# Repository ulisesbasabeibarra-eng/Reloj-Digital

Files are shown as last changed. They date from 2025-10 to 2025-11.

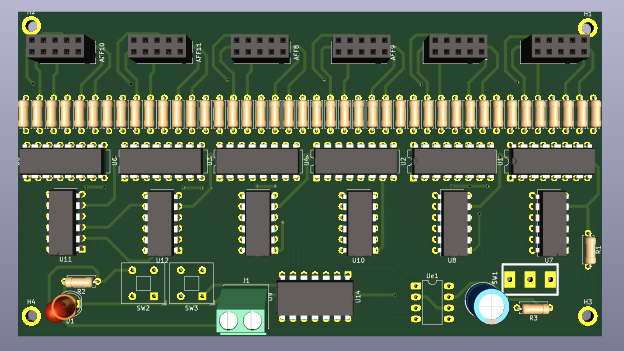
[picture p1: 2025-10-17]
placa/3D.png

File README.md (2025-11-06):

# Reloj Digital

(https://postimg.cc/QVPSPxDj)
## Authors

- [@Ulises Basabe](https://github.com/ulisesbasabeibarra-eng)
- [@Facundo Dominguez](https://github.com/facundodominguez1)
- [@Ramiro Trejo](https://github.com/RamiiTrejo)
- [@Rodrigo Benitez](https://github.com/rodrigobenitez17)
- [@Maximo Paez]()

## DESCRIPCIÓN

Un reloj digital sin utilizar un microcontrolador o web para establecer el tiempo. Utilizando solamente electronica discreta como el lm555, cuyo componente debe de estar en modo astable para general pulsos electronicos que estableceran gracias a los integrados 74LS47 y 74LS90 que los displays de 7 segmentos marquen una hora determinada. Un total de 6 displays para marcar los segundos, minutos y horas.
## Informe

[Video en proteus](https://www.youtube.com/watch?v=-MJHPHdGoc4)

[Reloj Digital](https://docs.google.com/document/d/12YXhhFJf7GPLBze2eZ5sYaiuNMOwRFxj9prBwNTrKLU/edit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)
. Este enlace lleva a un documento de google en el que se encuentra más informacion sobre este projecto junto con imagenes explicativas y vistas previas.
## Funcionamiento
El funcionamiento de este reloj se basa en el circuito integrado LM555, configurado como oscilador astable, que genera una serie de pulsos eléctricos aproximadamente de 1 Hz por  segundo. Estos pulsos son enviados al 74LS90, que actúa como contador decimal y convierte los pulsos en una salida binaria. Después, esta señal binaria pasa al 74LS47, que la decodifica y la transforma en señales para encender los segmentos correspondientes del display de 7 segmentos, mostrando así los números de forma digital. 

El potenciómetro permite ajustar la frecuencia del LM555, aumentando o disminuyendo la velocidad con que se generan los pulsos que llegan al 74LS90 (Es decir, la velocidad con que se cambian los números en el display).

El LED conectado al circuito también parpadea al ritmo de los pulsos, sirviendo como indicador visual de la frecuencia del contador. En este caso, se ha optado por utilizar una resistencia fija de 3,9 kΩ, de modo que el temporizador genere un pulso cada segundo aproximadamente, obteniendo así una base de tiempo estable para el reloj.

Los botones conectados uno a los displays de los segundos y otro conectado a los minutos. Su funcion es que una vez al ser pulsados, este pulso contara tambien como si fuera un pulso del LM555, es decir, una vez que se pulsa el numero del display pasara al siguiente respectivamente, funcionando como un reloj manual y esta para setiar el reloj a la hora exacta al de la hora actual.

(La alimentacion vendria mediante un cable conectado a un transformador el cual iria conectado a un toma corriente)
## Modelo 3D
En este projecto se utilizo Autodesk, plataforma de software el cual estoy mas acostumbrado a utilizar ademas de ser muy utilizadas a la hora de hacer diseños 3D, gracias a que este ofrece una amplia gama de software como AutoCAD, Fusion 360, Inventor y 3ds Max, utilizados en sectores como la ingeniería, la arquitectura, el entretenimiento y el diseño de productos.

El modelo 3D esta compuesto por dos partes principales: El piso y El cuerpo. 

El piso o la inferior, es un rectangulo compuesto por cuatro agujeros, uno en cada esquina, por donde se ingresarian los tornillos los cuales unirian las dos piezas. Además de tener otros cuatro agujeros más con un desnivel para ubicar la placa y mantenerla en el lugar y dejando un muy pequeño espacio entre los dos para las patas o sobresalientes de los componentes de la misma.

(https://postimg.cc/0KJsmph5)

El Cuepo tambien consta con los mismos huecos para tener mas rigidez en la uniones de estas tres partes (placa, piso, cuerpo).Tambien consta con un agujero en un costado para permitir la salida del cable de alimentación.

(https://postimg.cc/34FLqWpC)

Además tiene 6 agujeros rectangulares para permitir la vista de los displays de 7 segmento, con una pequeña separacion entre cada uno y otra entre cada grupo de dos, para formar los segundos, minutos y horas, cuyos grupos abajo les sigue sus respectivo unidad marcada como un corte en el cuerpo. Tambien, más abajo tiene dos agueros donde irian ubicados los botones. Los displays y los botones deberan ir adheridos con silicona para que mantengan su lugar.

(https://postimg.cc/LYGsr6pq)

En la carpeta carcasa, se encontran los archivos de estas pieza 3D en diferentes tipos de archivos desde .stl, donde se podran mandar a imprimir directamente, .fusion, asta .step. 
## Desmontaje de la carcasa
(https://a360.co/3W90Zk7)

 se observa como se vería el diseño de la plaqueta en 3D para poder dimensionar los componentes y facilitar la comprension de las conexiones

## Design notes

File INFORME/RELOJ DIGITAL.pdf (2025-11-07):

# RELOJ DIGITAL

Materia: Diseño Asistido y Simulación Electrónica

Profesor: Arguello Owen

Integrantes:
- Basabe Ulises
- Benitez Rodrigo
- Dominguez Facundo
- Paez Maximo
- Trejo Ramiro

Curso y división: 5°6 T.T

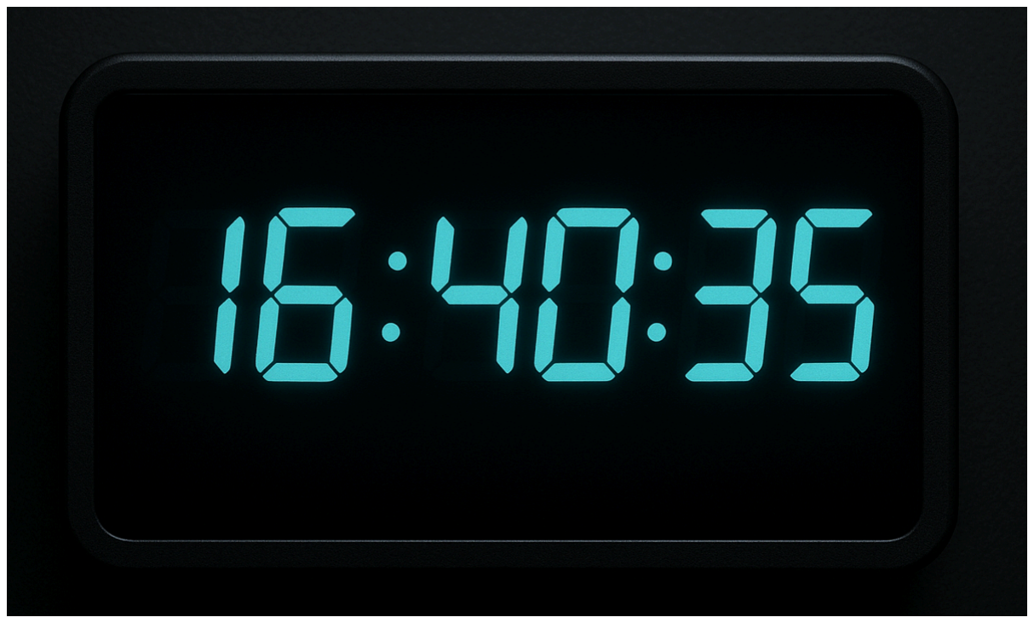
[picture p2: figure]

## PROYECTO

ÍNDICE:

PROYECTO | 2
INTRODUCCIÓN: | 3
FUNCIONAMIENTO | 3
DIAGRAMA DE FLUJO | 9
COMPONENTES | 10
SIMULACIÓN | 19
ESQUEMÁTICO | 26
PCB | 30
MODELO EN 3D (PCB) | 31
GABINETE | 32
GITHUB | 39
CONCLUSIÓN | 39

## INTRODUCCIÓN:

Este informe se basa en la idea de realizar un Reloj Digital sin el uso de un microcontrolador y con la utilización la electrónica discreta, por lo que en lugar del microcontrolador se emplean componentes lógicos tales como los integrados CD4081 (integrado de compuertas AND) 74LS32 (integrado de compuertas OR), 74LS47, 74LS90 y LM555, entre otros. Para luego hacer su esquemático, PCB, y la impresión 3D (Gabinete), la explicación de su funcionamiento, además del diagrama de flujos como explicación del funcionamiento del proyecto.

## FUNCIONAMIENTO

El funcionamiento de este reloj se basa en un circuito integrado LM555, configurado como oscilador astable, que genera una serie de pulsos eléctricos aproximadamente de 1 Hz por segundo. Estos pulsos son enviados al 74LS90, que actúa como contador decimal y convierte los pulsos en una salida binaria. Después, esta señal binaria pasa al 74LS47, que la decodifica y la transforma en señales (0 y 1 lógicos) para encender los segmentos correspondientes del display de 7 segmentos, mostrando así los números de forma digital.

El potenciómetro permite ajustar la frecuencia del LM555, aumentando o disminuyendo la velocidad con que se generan los pulsos que llegan al 74LS90 (Es decir, la velocidad con que se cambian los números en el display).

El LED conectado al circuito también parpadea al ritmo de los pulsos, sirviendo como indicador visual de la frecuencia del contador. En este caso, se ha optado por utilizar una resistencia fija de 3,9 kΩ, de modo que el temporizador genere un pulso cada segundo aproximadamente, obteniendo así una base de tiempo estable para el reloj.

## FUNCIONAMIENTO DE LOS COMPONENTES

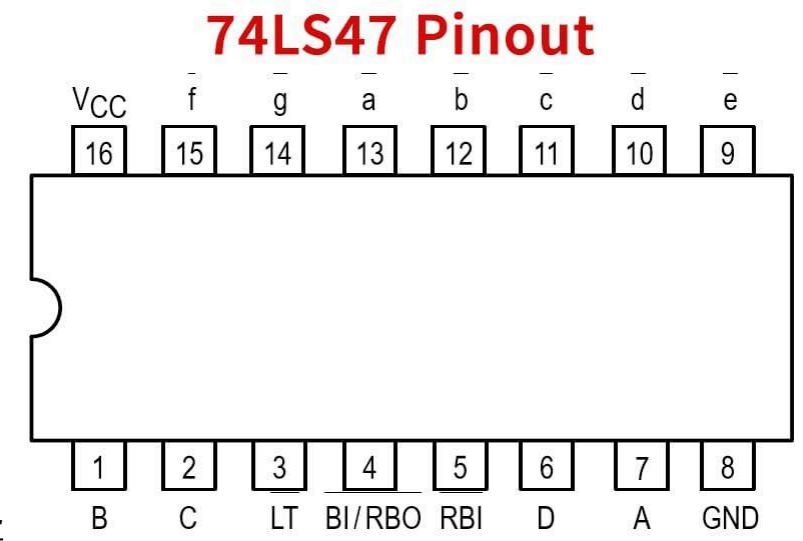
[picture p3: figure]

74LS47:

El 74LS47 es un decodificador/driver para un display de 7 segmentos de cátodo común, convierte un número binario de 0 a 9 en código BCD (código binario), en las señales necesarias para mostrarlo de forma visual en el display

1. A–D (pines 7,1,2,6): entran desde el contador → llevan el número en binario.
2. LT, RBI, BI (pines 3,4,5): todos a Vcc → se desactivan funciones extra.
3. a–g (pines 9–15): van al display → forman el número visible.
4. Vcc y GND (16 y 8): alimentación 5 V.

74LS90:

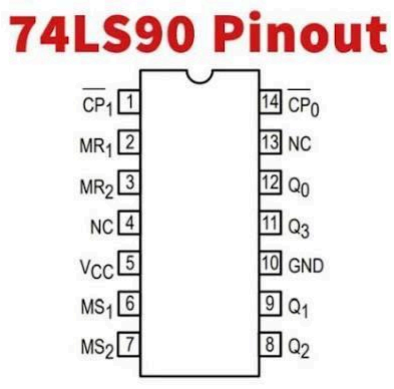
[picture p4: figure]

El 74LS90 es un contador de pulsos (señales de reloj) de 0 a 9 en binario , y después vuelve a cero automáticamente, Por eso se lo llama contador BCD, (generalmente se usa para contadores digitales como relojes, cronómetros etc. y también se combina como en este caso con el 74LS47 para mostrar los números en el display de 7 segmentos.

Pin 14 (CP1 o CLKA) → Entrada de reloj (clock).

Pin 1 (CP0 o CLKB) → Entrada de reloj secundaria.

Pin 2 (R0(1)) y Pin 3 (R0(2)) → Reset asíncrono. (Pin de reset)

Pin 6 (R9(1)) y Pin 7 (R9(2)) → Set asíncrono a 1001 (decimal 9).

Pin 12 (Q0), Pin 9 (Q1), Pin 8 (Q2), Pin 11 (Q3)

Son las salidas binarias del contador.

Van conectadas directamente a las entradas A–D del 74LS47.

Pin 5 (GND) → Masa del circuito.

Pin 10 (Vcc) → +5 V.

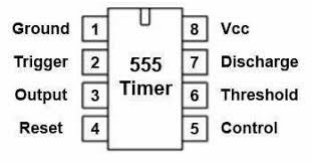
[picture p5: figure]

LM555:

El LM555 es un temporizador / generador de pulsos que trabaja de tres maneras principales:

Monoestable: Genera un solo pulso de duración fija

Astable: Genera una onda cuadrada continua como si fuera un reloj o parpadeo

Biestable: Funciona como un flip flop es decir, enciende o apaga una salida

1. GND (pin 1) → A tierra (masa).

Referencia de voltaje.

2. TRIG (pin 2) → Disparo del comparador.
3. OUT (pin 3) → Salida de onda cuadrada.

Va hacia los contadores (74LS90) → genera los pulsos de conteo.

También va al LED (con R2) para ver el parpadeo.

4. RESET (pin 4) → Reinicia el temporizador.

Lo tienes a Vcc (5V) para desactivarlo (no quieres resetear el oscilador).

5. CTRL (pin 5) → Voltaje de control.

Está conectado a tierra con un capacitor de desacoplo (no se usa en esta aplicación).

6. THR (pin 6) → Umbral del comparador.

Se conecta al capacitor (C1) y al pin 2 (TRIG).

7. DIS (pin 7) → Descarga.

Se conecta entre el capacitor y la resistencia/potenciómetro → controla la descarga del capacitor C1.

8. VCC (pin 8) → Alimentación (+5 V).

### DIAGRAMA DE FLUJO

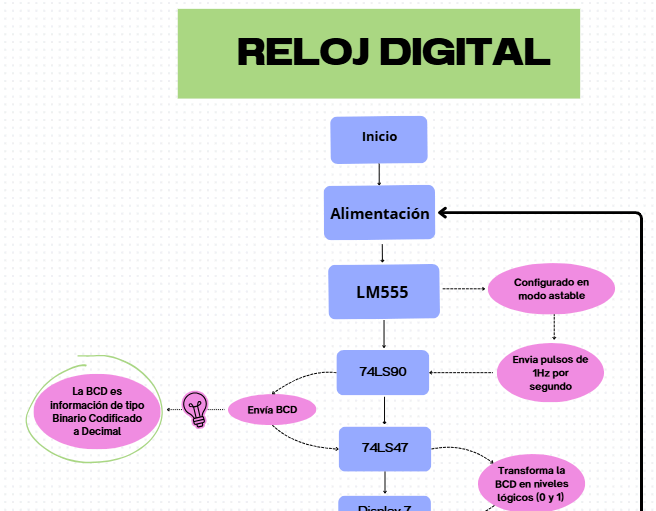
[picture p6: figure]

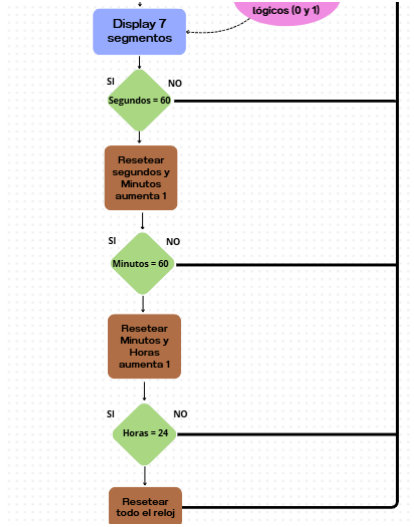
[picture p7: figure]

En este diagrama de flujo se puede observar cómo funciona el Reloj Digital de una manera fácil y sencilla

### COMPONENTES

COMPONENTE | CANTIDAD | IMAGEN DE REFERENCIA

Pineras doble fila (2x05) | 6
Pineras hembra doble fila (2x02) | 2
Zócalo 8 pines (2x04) | 1
Zócalo 12 pines (2x06) | 6

Zócalo 14 pines (2x07) | 7
Zócalo 16 pines (2x08) | 6
Resistencia SMD 330Ω 1206 | 43
Resistencia SMD 4,7kΩ 1206 | 1
Resistencia SMD 3.9kΩ 1206 | 1

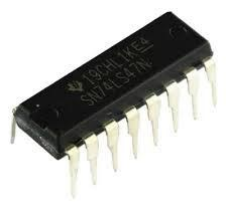
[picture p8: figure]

74LS47 | 6
74LS90 | 6
LM555 | 1

CD4081 | 2
74LS32 | 5
Led | 1

Capacitor (10uF) | 1
Displays de 7 segmentos | 6

## SIMULACIÓN

Para la parte de la simulación y pruebas del proyecto Reloj Digital se utilizó el software de simulación y diseño de plaquetas Proteus, el cuál incluye una amplia variedad de componentes electrónicos y una interfaz muy intuitiva.

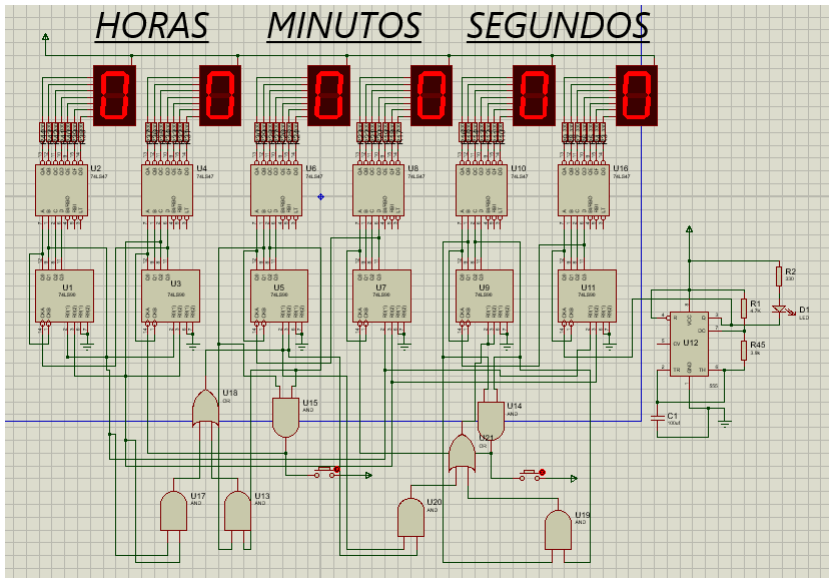
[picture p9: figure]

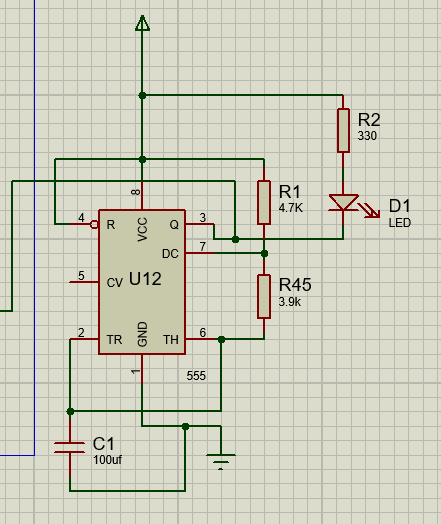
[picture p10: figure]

En esta imagen se muestra como es la conexión del LM555 para que genere los pulsos en modo astable.

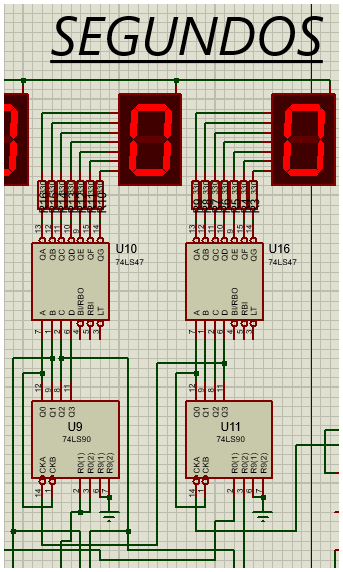
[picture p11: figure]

En esta otra se muestra como los pulsos son recibidos por el primer 74LS90 de todo el circuito (el de los segundos), que recibe los pulsos y los convierte en BCD (decimal codificado en binario en español) para que el 74LS47 transforme esos números en binario en señales (señales lógicas, 0 y 1) dando como resultado un número determinado. Luego mediante el pin de “carry out” (que indica un desbordamiento en este caso de bits) cuando este llega al número 9 (1001 en binario) genera el “carry out” y hace que aumente las decenas de segundos para que luego cuando este llegue a 5 y las unidades de segundos lleguen a 9 el próximo número sea un 1 en las unidades de los minutos.

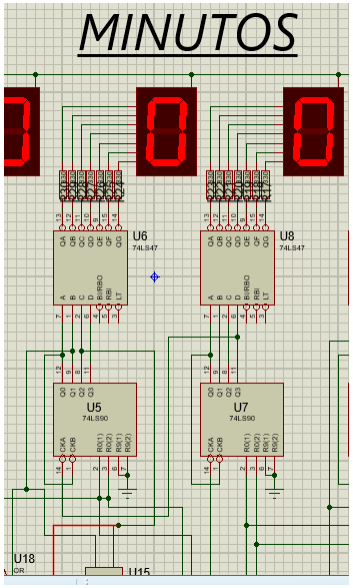
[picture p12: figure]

Este posee la misma funcionalidad que los segundos con la diferencia que posee un pulsador con el que se puede setear los minutos y que cuando llegue a 59 y los segundos esten en 59, el siguiente pulso aumentará las unidades de las horas

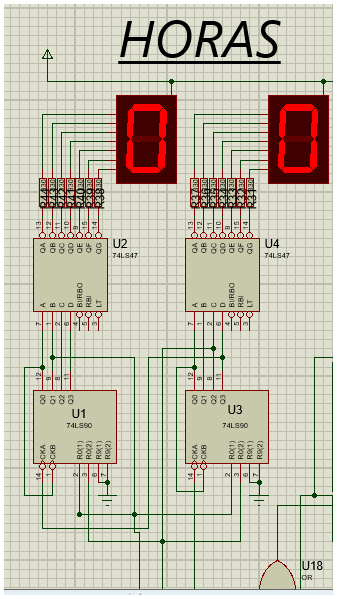
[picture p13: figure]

Este posee una lógica similar solamente que las unidades de horas llegan hasta 3 y las decenas llegan a 2 teniendo que por consecuencia cuando la hora marque 24 Horas el siguiente número será el reseteo del reloj, volviendo así a comenzar.

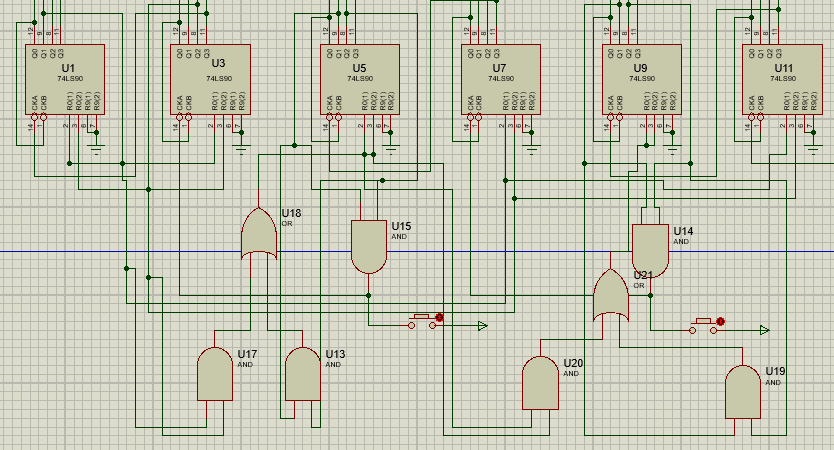
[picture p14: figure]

Aquí se muestra como en las horas y los minutos está la opción para setearlos mediante los pulsadores.
El seteo de la hora se basa en enviar pulsos manuales a las entradas de reloj de los contadores 74LS90, que de igual manera se da cuando los minutos o los segundos llegan a 60, haciendo que aumente las horas o los minutos.

Luego para hacer que se reseteen se hace cuando cualquiera de las dos condiciones se de, cuando los minutos alcanzan 60 o cuando las horas llegan a 24.
Esto se logra conectando la salida de la OR a los pines de reset de los contadores (R₁ y R₂) del 74LS90.
De esta forma, el circuito puede volver a cero automáticamente. Las compuertas AND se utilizan para cuando se dan las opciones de reseteo se marque como un uno lógico y esa señal se envía luego a la compuerta OR, que activa los pines de reset de los contadores, haciendo que los minutos (o segundos) vuelvan a cero. Lo mismo sucede cuando se llega a 24 (en las horas) haciendo que se resetee todo el reloj

En el siguiente enlace se muestra el funcionamiento del proyecto Reloj Digital simulado en Proteus: https://www.youtube.com/watch?v=-MJHPHdGoc4

## ESQUEMÁTICO

El diseño esquemático para la placa se realizó en el software de diseño de placas KICAD, el cual con suma facilidad permite diseñar el esquema y conexiones de componentes, con una interfaz muy intuitiva y una amplia variedad de diseños de componentes.

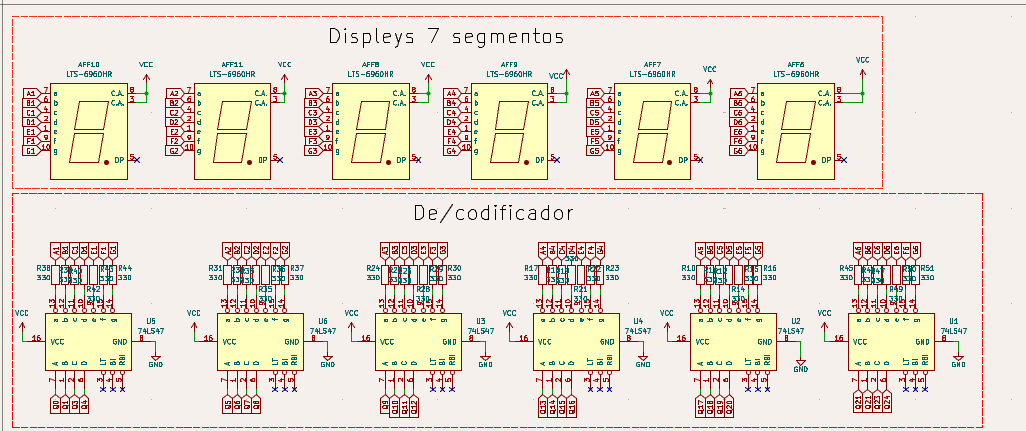
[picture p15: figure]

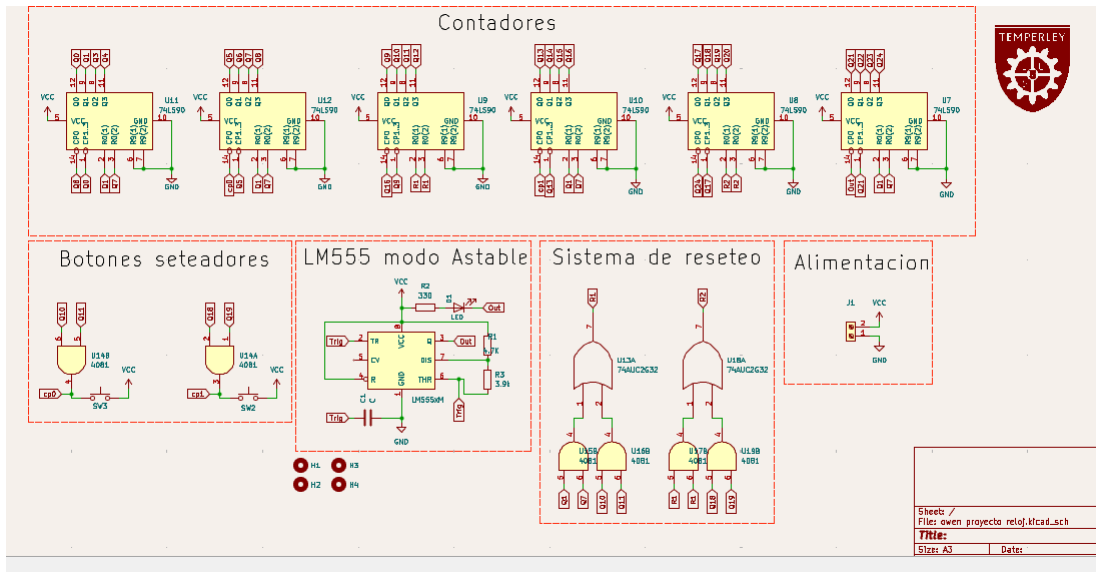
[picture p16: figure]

Y acá se encuentran fotos del esquemático (declaración de pines, decodificadores displays, integrados, etc)

Lo siguiente sería cómo se compone cada parte en general, primero viene el 74LS90, después le sigue el 74LS47 y por último los displays

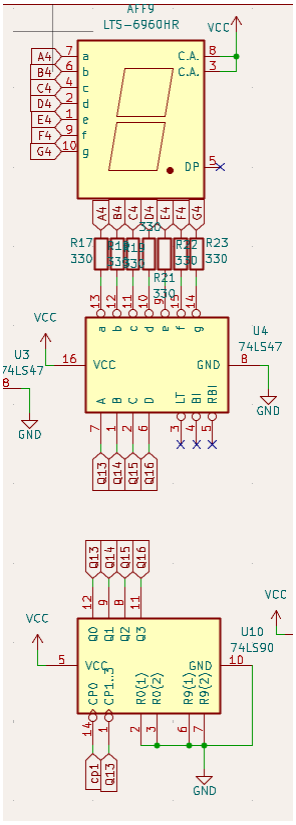
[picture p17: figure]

## PCB

El diseño PCB (placa de circuito impreso en español) se realizó de igual manera en la plataforma de software libre KICAD el cual además de poder realizar esquemas de diseños, también se puede realizar el diseño de la PCB, el cual posee una amplia variedad de huellas (formas de los componentes).
El diseño de la PCB se compone de la siguiente manera

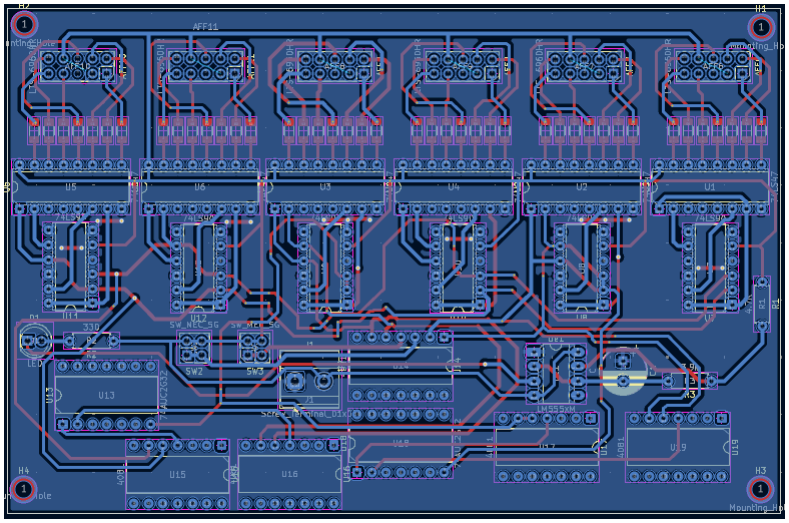
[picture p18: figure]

De esta forma queda el diseño para no desperdiciar espacio y mantener una mejor optimización de los componentes.

## MODELO EN 3D (PCB)

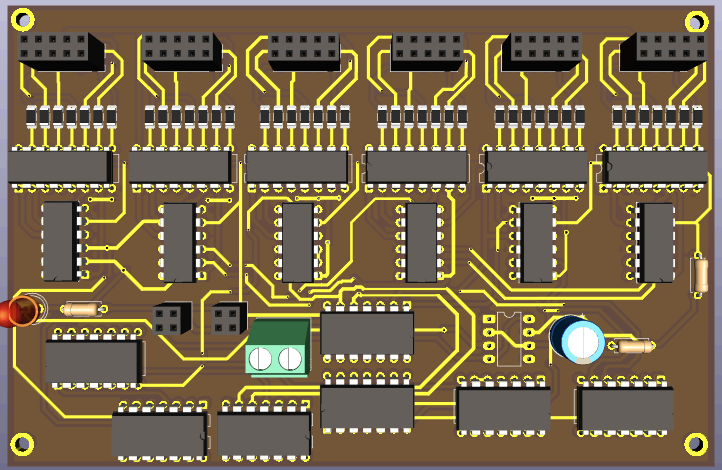
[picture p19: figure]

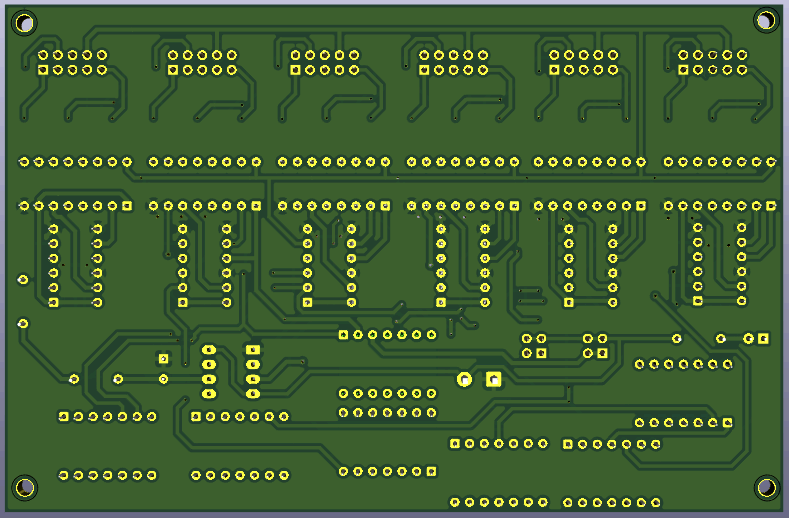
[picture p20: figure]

De esta manera se observa como es la distribución de los componentes desde un diseño de plaqueta de doble cara (también conocido como doble faz) para una mejor optimización y eficiencia del espacio.

## GABINETE

Este diseño se realizó en la aplicación de software de diseño 3D profesional, Autodesk Fusión 360, la cual posee una gran cantidad de herramientas para realizar diseños de tal magnitud, y con una mayor precisión que otros softwares de diseño.
Ahora veremos el modelo 3D del gabinete para poner los displays, la placa y como conectarse a la alimentación.

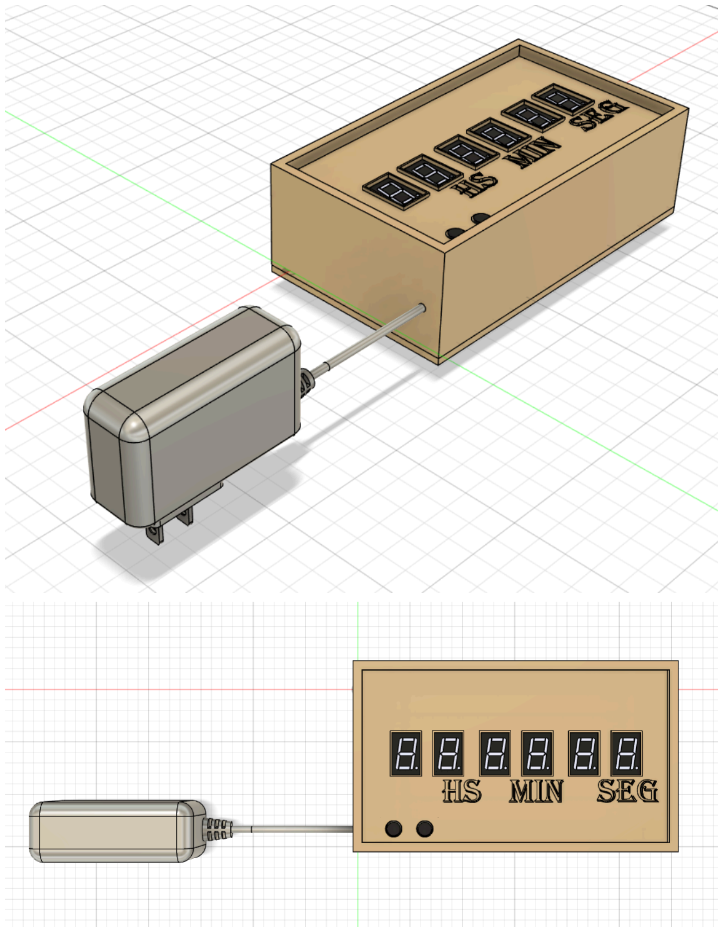
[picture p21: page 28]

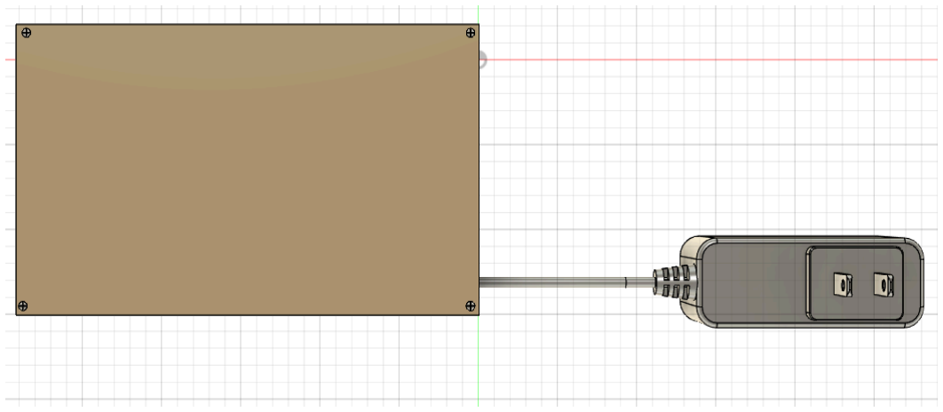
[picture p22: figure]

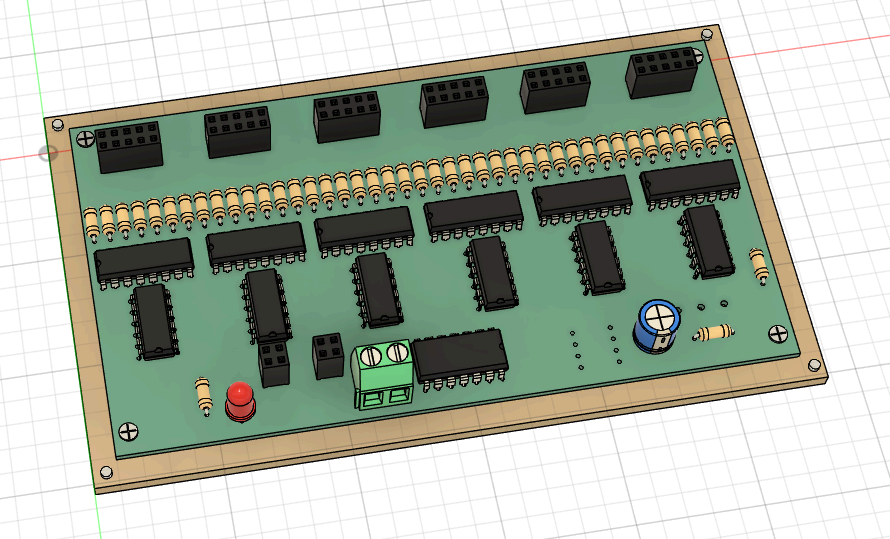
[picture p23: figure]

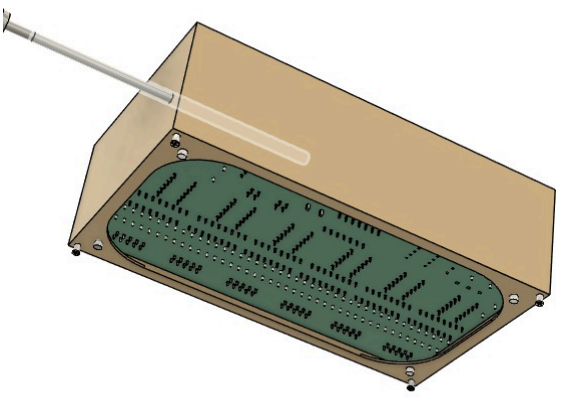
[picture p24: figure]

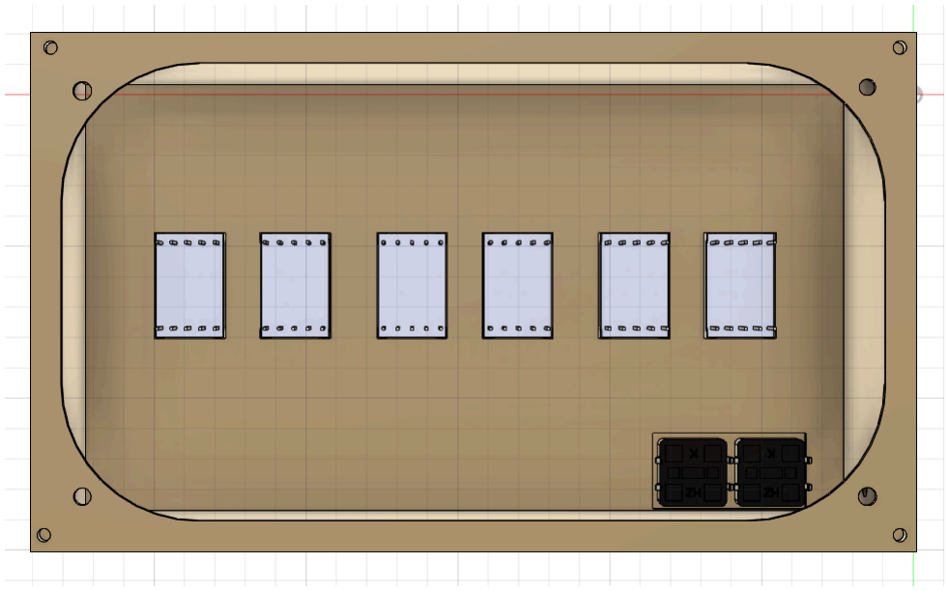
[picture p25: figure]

## GITHUB

A continuación se deja el enlace a la plataforma GITHUB donde se ha subido todo el proyecto y que permite visualizar las diferentes categorías del proyecto, y poder realizar las pruebas por cuenta propia.
https://github.com/ulisesbasabeibarra-eng/Reloj-Digital

## CONCLUSIÓN

Este proyecto permitió poner en práctica los conocimientos adquiridos en electrónica, aplicándolos de manera concreta en la realización de un reloj de 24 horas. A lo largo del desarrollo se pudo comprender de forma más profunda el funcionamiento interno de los distintos componentes electrónicos que componen la electrónica discreta, especialmente los circuitos integrados que hacen posible la secuencia y el conteo de tiempo. Además de poder profundizar el aprendizaje en las aplicaciones tanto como de simulación del circuito, como de la creación de la PCB o el diseño 3D

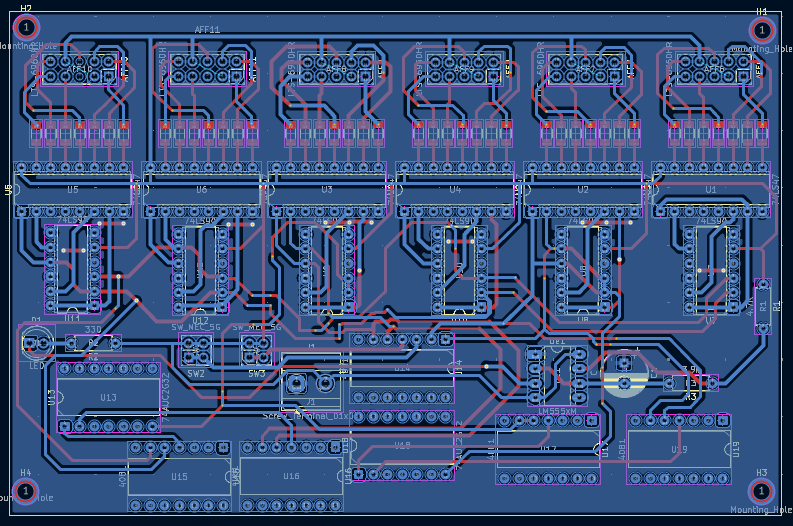
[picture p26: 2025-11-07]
placa/PCB.png

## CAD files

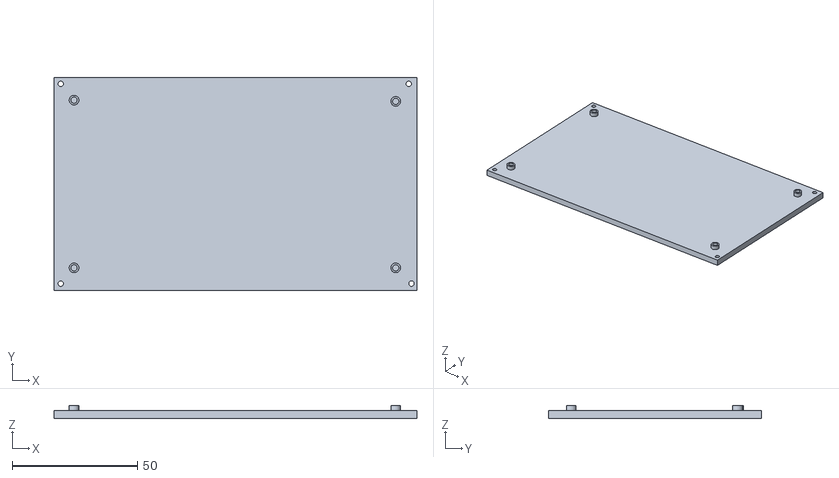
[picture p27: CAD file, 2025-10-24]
Carcasa/Objetos 3d/Reloj carcasa piso.stl
145.0 x 85.0 x 5.00

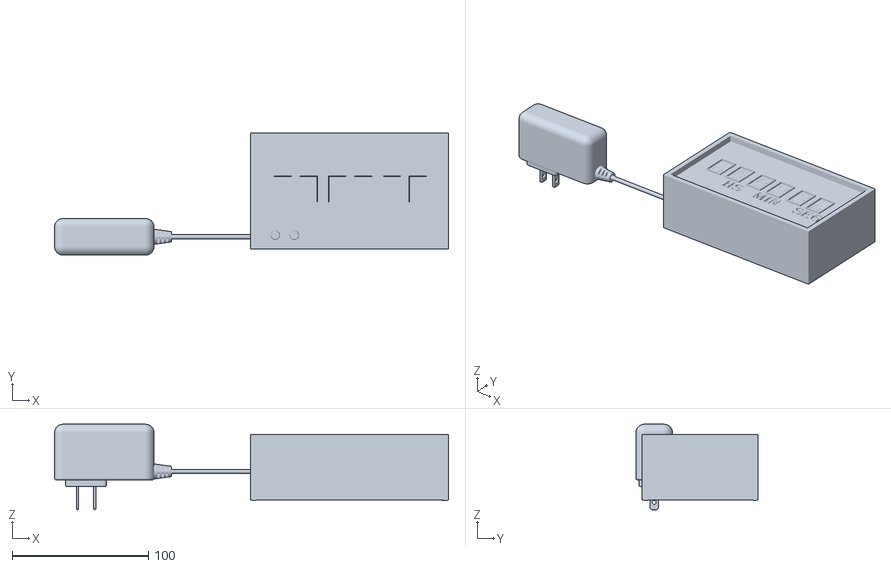
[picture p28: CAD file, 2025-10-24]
Carcasa/Reloj carcasa v10.stl
288.8 x 89.7 x 62.8

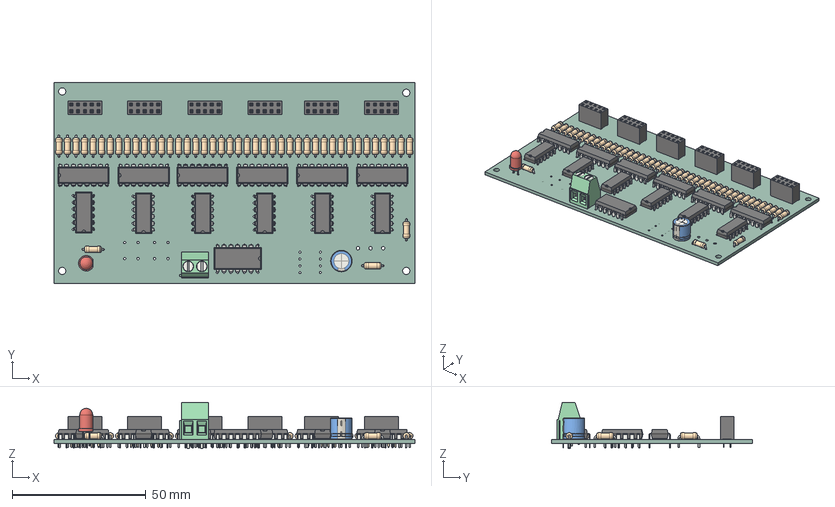
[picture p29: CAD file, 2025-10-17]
placa/pcb y esquematico/owen proyecto reloj.step
134.8 x 74.9 x 17.3 mm
R_Axial_DIN0207_L6.3mm_D2.5mm_P7.62mm_Horizontal x 45
PinSocket_2x05_P2.54mm_Vertical x 6
DIP-16_W7.62mm x 6
DIP-12_W7.62mm x 6
LED_D5.0mm
CP_Radial_D8.0mm_P3.50mm
DIP-14_W10.16mm
TerminalBlock_Phoenix_MKDS-1,5-2-5.08_1x02_P5.08mm_Horizontal
owen proyecto reloj_PCB

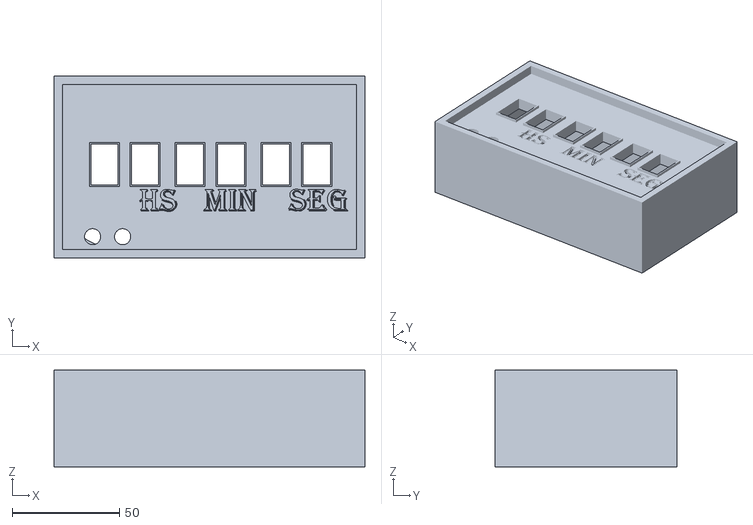
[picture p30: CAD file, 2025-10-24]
Carcasa/Objetos 3d/Reloj carcasa cuerpo.stl
145.0 x 85.0 x 45.0

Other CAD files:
Carcasa/Reloj carcasa v9.f3z

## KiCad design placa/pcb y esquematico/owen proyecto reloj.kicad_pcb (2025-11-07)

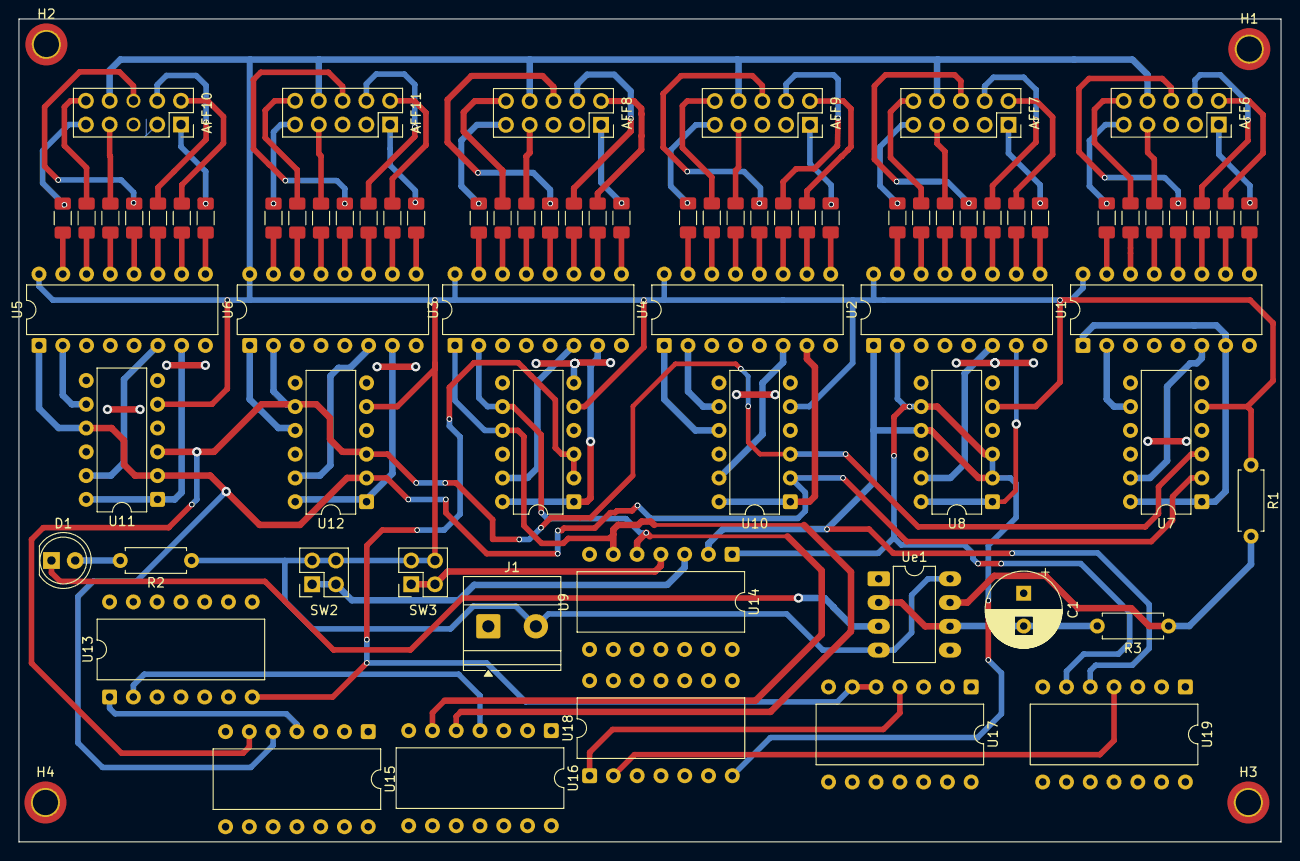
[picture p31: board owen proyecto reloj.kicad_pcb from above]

Board: 2 copper layers, 134.8 x 87.9 mm, 80 parts (0 on the bottom side), 121 nets.

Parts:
AFF6, AFF7, AFF8, AFF9, AFF10, AFF11: LTS-6960HR; PinSocket_2x05_P2.54mm_Vertical
C1: C; CP_Radial_D8.0mm_P3.50mm
D1: LED; LED_D5.0mm
H1, H2, H3, H4: Mounting_Hole; MountingHole_2.7mm_M2.5_ISO14580_Pad_TopOnly
J1: Screw_Terminal_01x02; TerminalBlock_Phoenix_MKDS-1,5-2-5.08_1x02_P5.08mm_Horizont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
R1: 4.7K; R_Axial_DIN0207_L6.3mm_D2.5mm_P7.62mm_Horizontal
R2: 330; R_Axial_DIN0207_L6.3mm_D2.5mm_P7.62mm_Horizontal
R3: 3.9k; R_Axial_DIN0207_L6.3mm_D2.5mm_P7.62mm_Horizontal
R10, R11, R12, R13, R14, R15, R16, R17, R18, R19, R20, R21, R22, R23, R24, R25, R26, R27, R28, R29, R30, R31, R32, R33, R34, R35, R36, R37, R38, R39, R40, R41, R42, R43, R44, R45, R46, R47, R48, R49, R50, R51: 330; R_1206_3216Metric_Pad1.30x1.75mm_HandSolder
SW2, SW3: SW_MEC_5G; PinSocket_2x02_P2.54mm_Vertical
U1, U2, U3, U4, U5, U6: 74LS47; DIP-16_W7.62mm
U7, U8, U9, U10, U11, U12: 74LS90; DIP-12_W7.62mm
U13, U18: 74AUC2G32; DIP-14_W10.16mm
U14, U15, U16, U17, U19: 4081; DIP-14_W10.16mm
Ue1: LM555xM; DIP-8_W7.62mm_LongPads

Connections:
A1: AFF10.7 (a), R38.1
A2: AFF11.7 (a), R31.1
A3: AFF8.7 (a), R24.1
A4: AFF9.7 (a), R17.1
A5: AFF7.7 (a), R10.1
A6: AFF6.7 (a), R45.1
B1: AFF10.6 (b), R39.1
B2: AFF11.6 (b), R32.1
B3: AFF8.6 (b), R25.1
B4: AFF9.6 (b), R18.1
B5: AFF7.6 (b), R11.1
B6: AFF6.6 (b), R46.1
C1: AFF10.4 (c), R40.1
C2: AFF11.4 (c), R33.1
C3: AFF8.4 (c), R26.1
C4: AFF9.4 (c), R19.1
C5: AFF7.4 (c), R12.1
C6: AFF6.4 (c), R47.1
D1: AFF10.2 (d), R41.1
D2: AFF11.2 (d), R34.1
D3: AFF8.2 (d), R27.1
D4: AFF9.2 (d), R20.1
D5: AFF7.2 (d), R13.1
D6: AFF6.2 (d), R48.1
E1: AFF10.1 (e), R42.1
E2: AFF11.1 (e), R35.1
E3: AFF8.1 (e), R28.1
E4: AFF9.1 (e), R21.1
E5: AFF7.1 (e), R14.1
E6: AFF6.1 (e), R49.1
F1: AFF10.9 (f), R43.1
F2: AFF11.9 (f), R36.1
F3: AFF8.9 (f), R29.1
F4: AFF9.9 (f), R22.1
F5: AFF7.9 (f), R15.1
F6: AFF6.9 (f), R50.1
G1: AFF10.10 (g), R44.1
G2: AFF11.10 (g), R37.1
G3: AFF8.10 (g), R30.1
G4: AFF9.10 (g), R23.1
G5: AFF7.10 (g), R16.1
G6: AFF6.10 (g), R51.1
GND: C1.1, J1.1, U1.8 (GND), U2.8 (GND), U3.8 (GND), U4.8 (GND), U5.8 (GND), U6.8 (GND), U7.6 (R9(1)), U7.7 (R9(2)), U7.10 (GND), U8.6 (R9(1)), U8.7 (R9(2)), U8.10 (GND), U9.6 (R9(1)), U9.7 (R9(2)), U9.10 (GND), U10.6 (R9(1)), U10.7 (R9(2)), U10.10 (GND), U11.6 (R9(1)), U11.7 (R9(2)), U11.10 (GND), U12.6 (R9(1)), U12.7 (R9(2)), U12.10 (GND), Ue1.1 (GND)
unnamed: D1.2 (A), R2.2
unnamed: R45.2, U1.13 (a)
unnamed: R46.2, U1.12 (b)
unnamed: R47.2, U1.11 (c)
unnamed: R48.2, U1.10 (d)
unnamed: R49.2, U1.9 (e)
unnamed: R50.2, U1.15 (f)
unnamed: R51.2, U1.14 (g)
unnamed: R10.2, U2.13 (a)
unnamed: R11.2, U2.12 (b)
unnamed: R12.2, U2.11 (c)
unnamed: R13.2, U2.10 (d)
unnamed: R14.2, U2.9 (e)
unnamed: R15.2, U2.15 (f)
unnamed: R16.2, U2.14 (g)
unnamed: R24.2, U3.13 (a)
unnamed: R25.2, U3.12 (b)
unnamed: R26.2, U3.11 (c)
unnamed: R27.2, U3.10 (d)
unnamed: R28.2, U3.9 (e)
unnamed: R29.2, U3.15 (f)
unnamed: R30.2, U3.14 (g)
unnamed: R17.2, U4.13 (a)
unnamed: R18.2, U4.12 (b)
unnamed: R19.2, U4.11 (c)
unnamed: R20.2, U4.10 (d)
unnamed: R21.2, U4.9 (e)
unnamed: R22.2, U4.15 (f)
unnamed: R23.2, U4.14 (g)
unnamed: R38.2, U5.13 (a)
unnamed: R39.2, U5.12 (b)
unnamed: R40.2, U5.11 (c)
unnamed: R41.2, U5.10 (d)
unnamed: R42.2, U5.9 (e)
unnamed: R43.2, U5.15 (f)
unnamed: R44.2, U5.14 (g)
unnamed: R31.2, U6.13 (a)
unnamed: R32.2, U6.12 (b)
unnamed: R33.2, U6.11 (c)
unnamed: R34.2, U6.10 (d)
unnamed: R35.2, U6.9 (e)
unnamed: R36.2, U6.15 (f)
unnamed: R37.2, U6.14 (g)
unnamed: U13.1, U15.4
unnamed: U13.2, U16.4
unnamed: U17.4, U18.1
unnamed: U18.2, U19.4
unnamed: R1.2, R3.1, Ue1.7 (DIS)
Out: D1.1 (K), Ue1.3 (Q)
Q0: U5.7 (A), U11.1 (CP1..3), U11.12 (Q0)
Q1: U5.1 (B), U7.2 (R0(1)), U10.2 (R0(1)), U11.2 (R0(1)), U11.9 (Q1), U12.2 (R0(1)), U15.5
Q3: U5.2 (C), U11.8 (Q2)
Q4: U5.6 (D), U11.11 (Q3)
Q5: U6.7 (A), U12.1 (CP1..3), U12.12 (Q0)
Q6: U6.1 (B), U12.9 (Q1)
Q7: U6.2 (C), U7.3 (R0(2)), U10.3 (R0(2)), U11.3 (R0(2)), U12.3 (R0(2)), U12.8 (Q2), U15.6
Q8: U6.6 (D), U12.11 (Q3)
Q9: U3.7 (A), U9.1 (CP1..3), U9.12 (Q0)
Q10: U3.1 (B), U9.9 (Q1), U14.6, U16.5
Q11: U3.2 (C), U9.8 (Q2), U14.5, U16.6
Q12: U3.6 (D), U9.11 (Q3)
Q13: U4.7 (A), U10.1 (CP1..3), U10.12 (Q0)
Q14: U4.1 (B), U10.9 (Q1)
Q15: U4.2 (C), U10.8 (Q2)
Q16: U4.6 (D), U10.11 (Q3)
Q17: U2.7 (A), U8.1 (CP1..3), U8.12 (Q0)
Q18: U2.1 (B), U8.9 (Q1), U14.2, U19.5
Q19: U2.2 (C), U8.8 (Q2), U14.1, U19.6
Q20: U2.6 (D), U8.11 (Q3)
Q21: U1.1 (B), U1.7 (A), U7.1 (CP1..3), U7.12 (Q0)
Q23: U1.2 (C), U7.8 (Q2)
Q24: U1.6 (D), U7.11 (Q3)
R1: U9.2 (R0(1)), U9.3 (R0(2)), U13.7, U17.5, U17.6
R2: U8.2 (R0(1)), U8.3 (R0(2)), U18.7
Trig: C1.2, R3.2, Ue1.2 (TR), Ue1.6 (THR)
VCC: AFF6.3 (C.A.), AFF6.8 (C.A.), AFF7.3 (C.A.), AFF7.8 (C.A.), AFF8.3 (C.A.), AFF8.8 (C.A.), AFF9.3 (C.A.), AFF9.8 (C.A.), AFF10.8 (C.A.), AFF11.3 (C.A.), AFF11.8 (C.A.), J1.2, R1.1, R2.1, SW2.3 (B), SW2.4 (B), SW3.3 (B), SW3.4 (B), U1.16 (VCC), U2.16 (VCC), U3.16 (VCC), U4.16 (VCC), U5.16 (VCC), U6.16 (VCC), U7.5 (VCC), U8.5 (VCC), U9.5 (VCC), U10.5 (VCC), U11.5 (VCC), U12.5 (VCC), Ue1.4 (R), Ue1.8 (VCC)
cp0: SW3.1 (A), SW3.2 (A), U14.4
cp1: SW2.1 (A), SW2.2 (A), U14.3

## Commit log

2025-10-25 ESQUEMATICO Y PCB README
2025-10-25 pcb y esq
2025-11-02 README
    Removed detailed section about schematic and PCB design using KICAD, including images and explanations.
